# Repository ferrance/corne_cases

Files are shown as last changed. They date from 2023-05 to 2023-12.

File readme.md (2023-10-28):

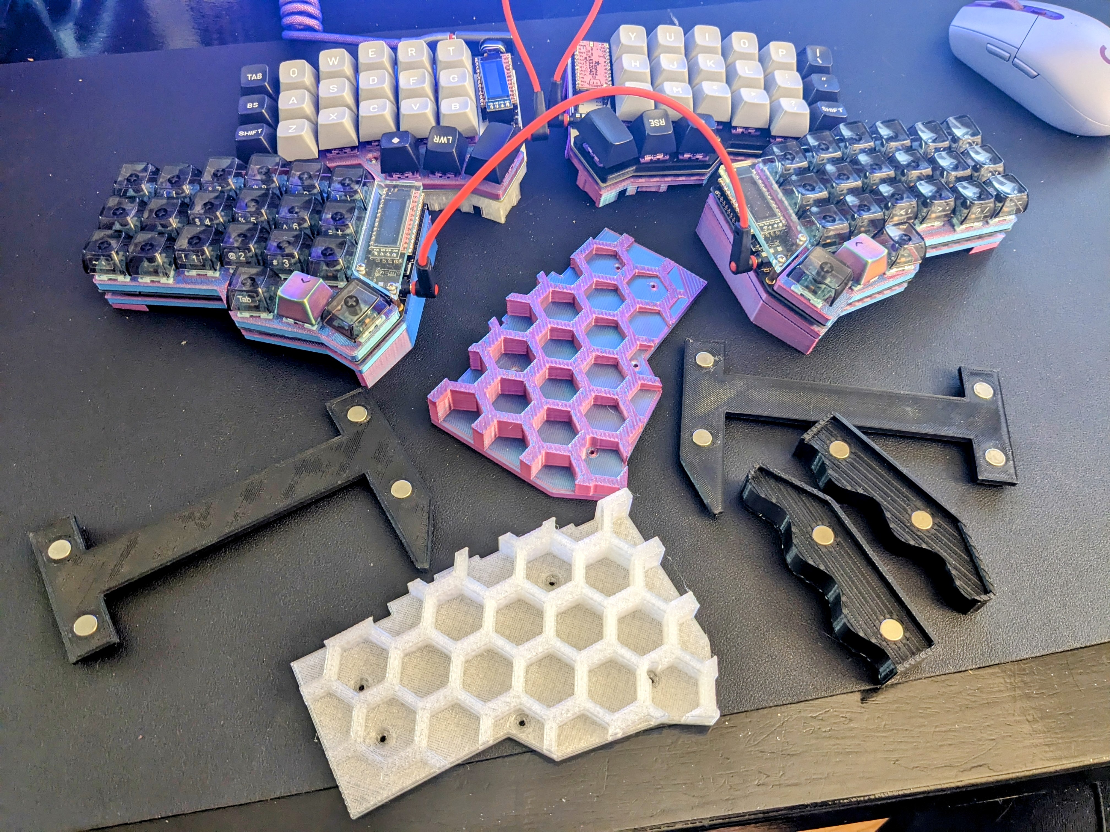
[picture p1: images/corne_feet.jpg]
image of crkbd


These are the various ways I have built my [corne keyboads](https://github.com/foostan/crkbd).
Over time it has evolved into more of a toolkit for corne-related projects in OpenSCAD.

# Source files

## crkbd.scad

This is the main library file that all of the projects are built on.

### crkbd3d(SCREWS=true)

This creates a bottom plate. It starts with the backplate_nofeet.stl file,
which it moves to a standard position in the upper right quadrant. It then
cuts out the screw holes. Doing this widens them slightly and makes sure that 
they are in the exact same spots as anything else done by this API.

### crkbd2d(SCREWS=true)

This creates a 2d profile of the PCB. The SCREWS parameter
controls whether or not it will include holes for the five
standoffs that the PCB allows for. The 2D profile is useful 
for making more complicated shapes.

This is basically a projection of crkbd3d().

## stl files
The project can be built from 3 files:
- corne_feet.scad
- cherryplate.stl
- backplate_nofeet.stl

The two STLs come from: https://thingiverse.com/thing:4459741

The scad file generates all of the other STLs.

# Projects

## stl-feet

## Pillars

This is sort of a bottom plate. It contains five pillars that are 
extruded 20 degrees around an axis to give it 20 degrees of tenting.
The pillars have holes that you can screw M2 screws into. I didn't 
thread these, they are just small enough that the screw will to that 
for you. The screws are meant to go down through the top plate and PCB
directly into the 3D printed object. 

I am using this with a fairly strange corne that i built with the 
controller on the bottom. It accomodates that nicely. This board 
also uses a 1.3" OLED. There is a separate mount for that included
in the project. But it would work just fine with normal OLEDs and controllers.

## Case

A quick and dirty box to store a corne in for travel. Before I built
this I actually lost a keyswitch and keycap when pulling the board out 
of a pocket in my laptop case. This should fix that.
# STL Files

- keyplate.stl

  the top plate that the cherry mx switches fit in. It does not
  matter what top plate you use, you can use the rest of these STLs
  with any top plate, even an FR4 or an acrylic plate.

- base_plate_flat.stl

  flat bottom plate with holes for 4 magnets. This is 
  the bottom plate to attach to keyplate.stl if you want
  to use the magnetic attachments.

- base_plate_5x5.stl

  a base plate with 5 degrees of tent ant 5 degrees of tilt.
  It does not use magnets. It is best for keebs that you don't 
  need to travel with. You can dial in an appropriate amount of
  tent and tilt in the SCAD file; 5x5 just happens to work nicely
  for me.
  
- corne_feet.stl

  These are small feet which attach via magnets to the magnetic
  bottom plate to provide some tenting.

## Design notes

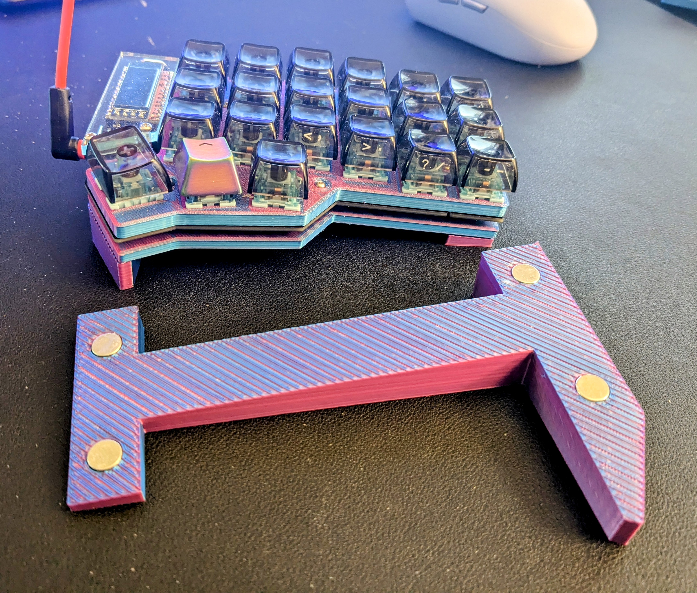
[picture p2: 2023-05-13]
images/close_up.jpg

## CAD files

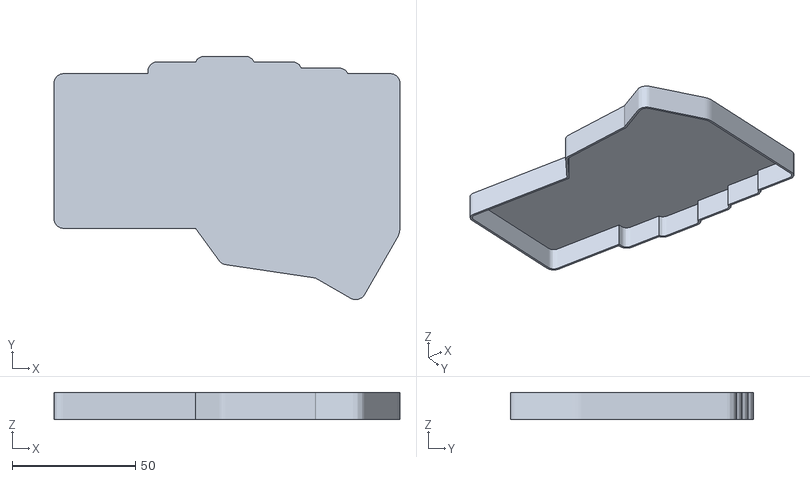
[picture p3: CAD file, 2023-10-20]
case/crkbd-cover.stl
140.2 x 98.5 x 11.0

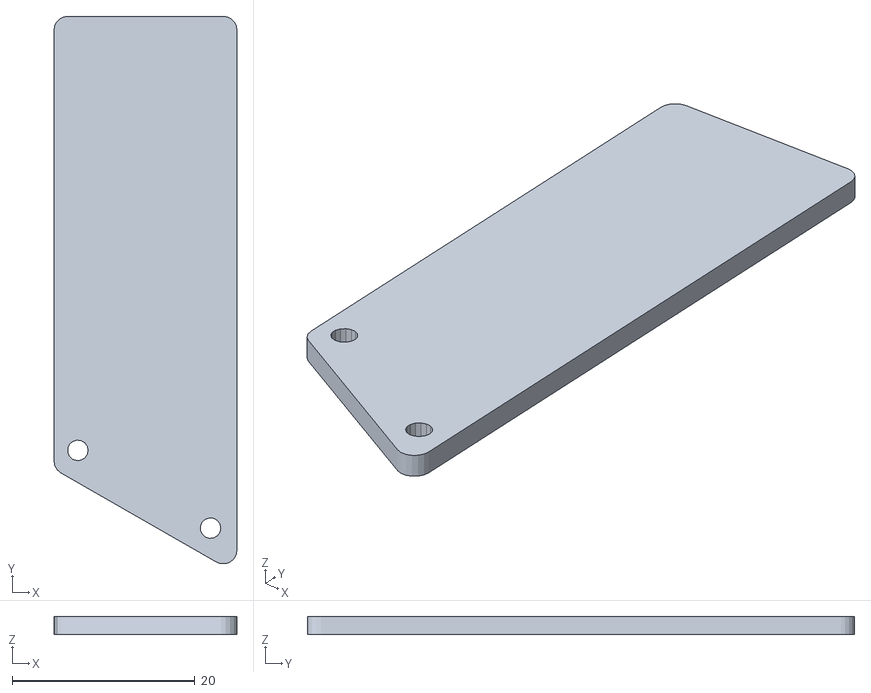
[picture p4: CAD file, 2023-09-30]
input/oled_cover.stl
20.0 x 59.8 x 2.00

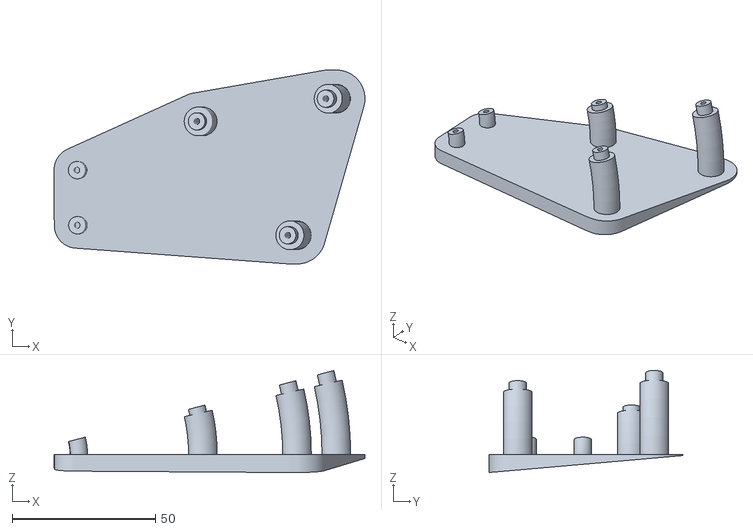
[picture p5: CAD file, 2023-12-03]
pillars/pillars-15.stl
108.4 x 67.6 x 35.6

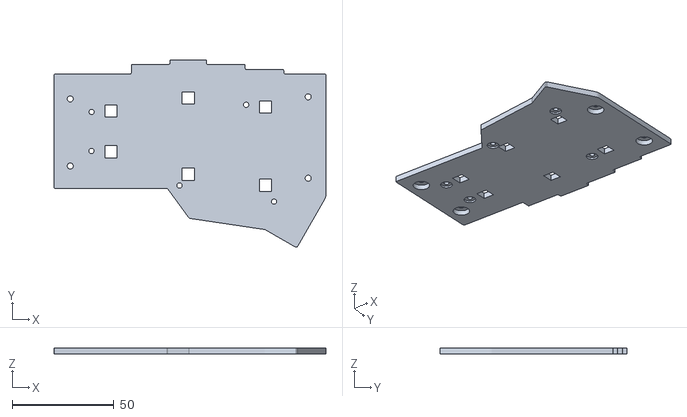
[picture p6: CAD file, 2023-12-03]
stl/base_plate_underglow.stl
133.8 x 92.2 x 3.00

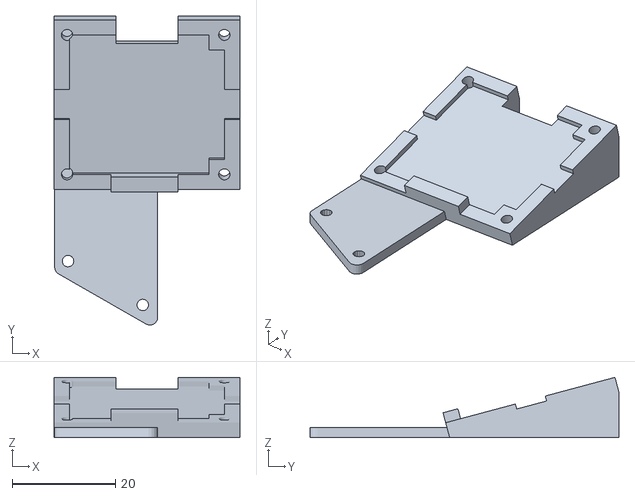
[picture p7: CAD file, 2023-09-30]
upsidedown/oled_cover_big.stl
36.0 x 59.9 x 11.7

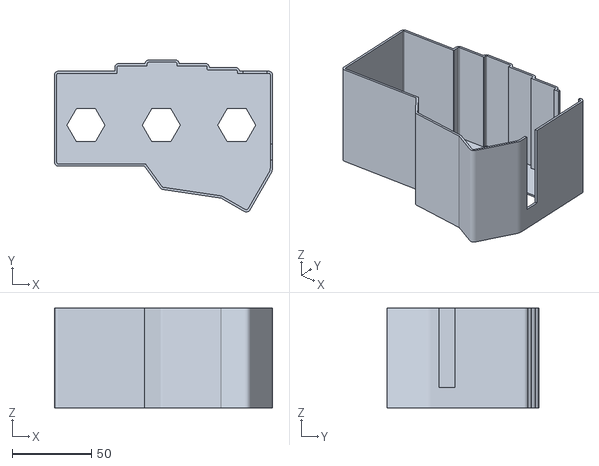
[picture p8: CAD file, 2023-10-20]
case/crkbd-case.stl
137.4 x 95.8 x 63.0

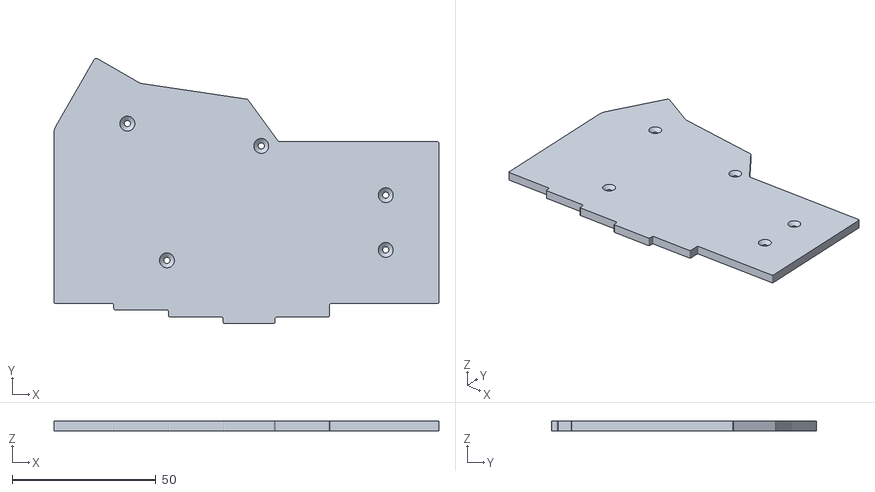
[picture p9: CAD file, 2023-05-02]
input/backplate_nofeet.stl
133.8 x 92.2 x 3.50

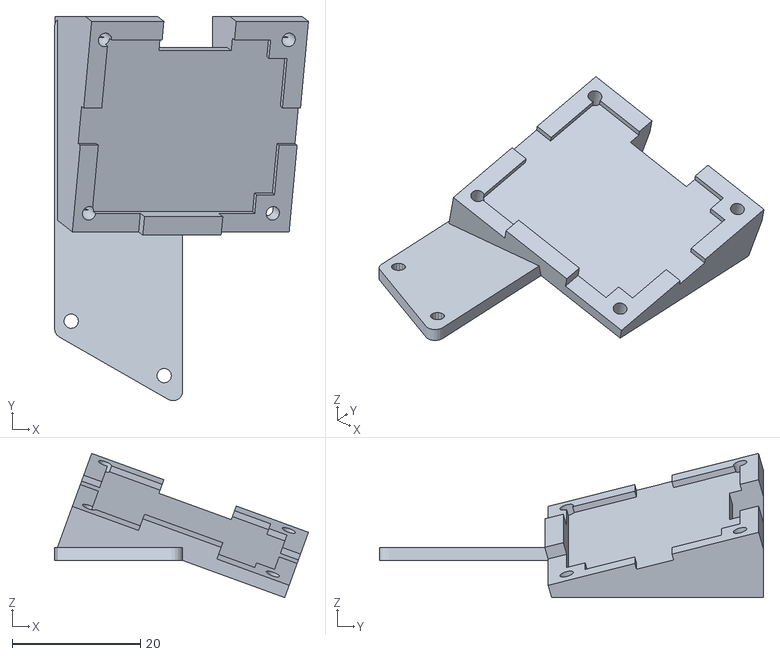
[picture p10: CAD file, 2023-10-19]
pillars/lcd-angled.stl
39.6 x 59.9 x 22.5

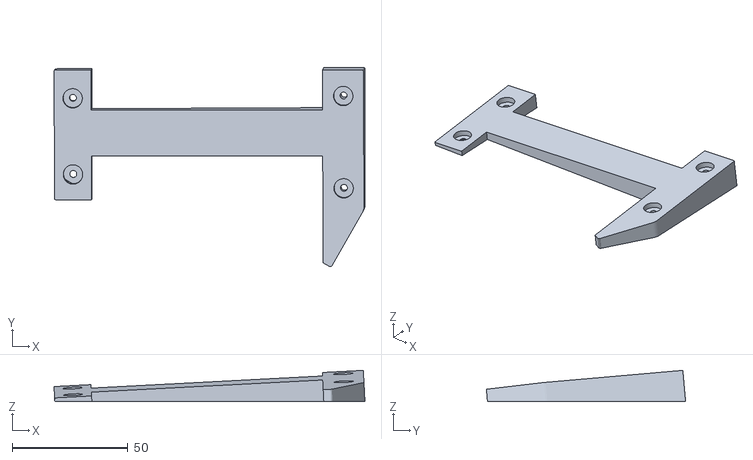
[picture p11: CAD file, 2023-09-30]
stl/base_plate_3x5.stl
134.3 x 86.0 x 13.5

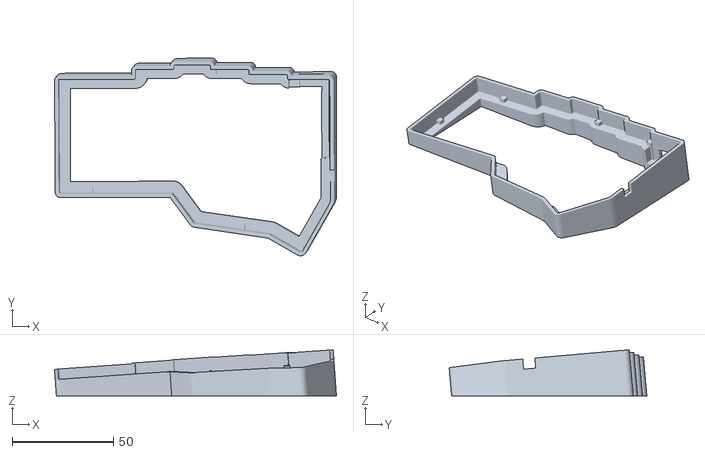
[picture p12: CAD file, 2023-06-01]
upsidedown/base_wo_ledge.stl
139.0 x 97.5 x 22.7

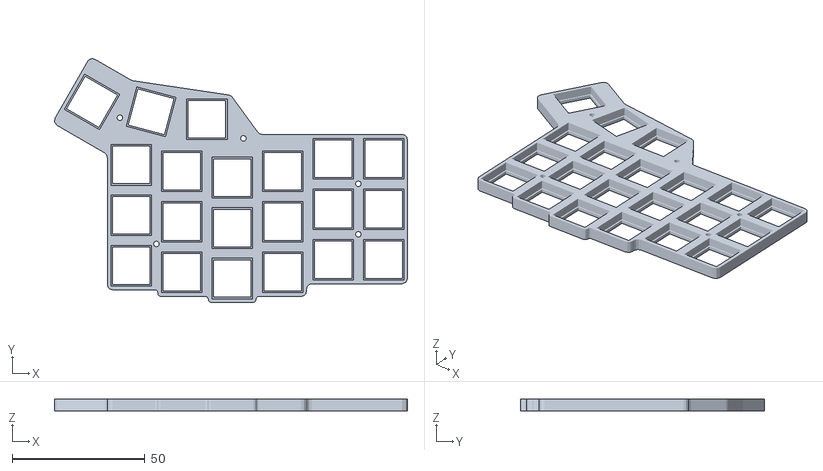
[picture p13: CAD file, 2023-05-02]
input/cherryplate.stl
132.9 x 91.8 x 4.50

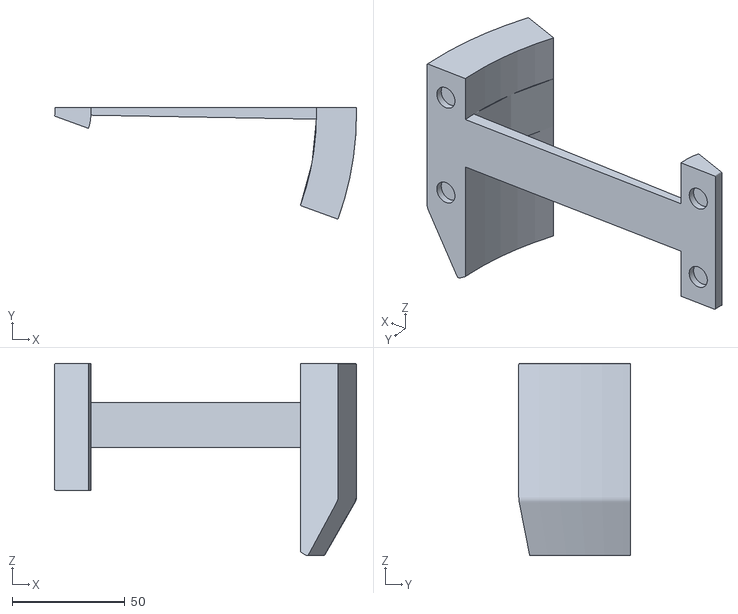
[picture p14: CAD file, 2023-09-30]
stl/base_plate_20x0.stl
133.9 x 49.4 x 85.2

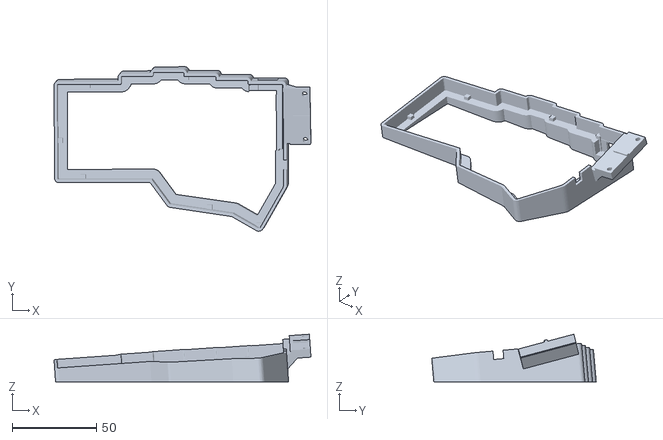
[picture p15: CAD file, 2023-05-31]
upsidedown/base.stl
152.3 x 97.5 x 28.2

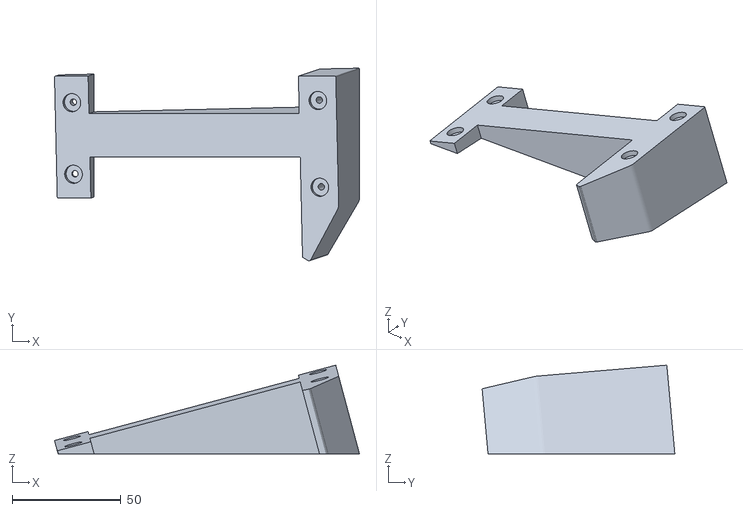
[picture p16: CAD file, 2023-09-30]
stl/base_plate_15x5.stl
140.1 x 88.5 x 40.7

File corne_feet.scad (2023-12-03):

// 2022 12 10    original design
// 2023 01 01    clean up terrible code, now it is just really bad
//               add one piece backplate and feet
//               made the ledge a little taller
// 2023 01 08    adding holes to allow magnets to be removed
//               more easily. Widen screw holes and inset them
//               got rid of the two middle magnets
// 2023 03 22    refactor everything, make a base plate with tent/tilt w/o magnets
//
// 2023 05 26    cleaning up the code
//
// 2023 09 05    adding round_magnets()
//
// 2023 12 02    added holes for underglow, refactoring
//
// Assumes these files are present:
//   - backplate_nofeet.stl (3.5mm tall)
//   - cherryplate.stl (4.5mm tall)

use <crkbd.scad>

$fn=10;

BASE_THICKNESS = 3.5;    // per slicer, measured is as high as 3.9, sigh
TOP_THICKNESS  = 4.5;    // ht of top plate
MAG_H = 2.6;  // measured ht of magnets 

// the top, with a border to snap into the bottom plate
// draws a 3.5mm high, 2mm wide border
// then subpracts a 1.5mm baseplate
// then rotates it all ANGLE DEGREES
// note that you can't put a 2.5mm magnet here because there's
// only 1mm of top to pet it in
//
// currently only called by wedge
//
module top() {
    ANGLE = 5;
    rotate([0,-ANGLE,0])
        difference() {
            linear_extrude(3.5) offset(r=2) k2d();
            translate([0,0,1]) linear_extrude(10) k2d();
        }
}

module wedge(magnets=false) {
    ANGLE = 5;
    difference() {
      union() {    
        // make a base that matches the projection of the top
        difference() {
          linear_extrude(20) projection() top();
          rotate([0,-ANGLE,0]) 
            translate([-10,0,0]) linear_extrude(30) square(200);
        }
      
        // now add the top
        top();
      } //union
      
      if (magnets) {
        rotate([0,-ANGLE,0]) translate([0,0,-1.59]) magnets();
      }
  } // difference

}

// these are the feet that attach to the insidbe magnets
// to provide some tenting
// 
// this was my original idea for tenting and portability. it
// still works but I prefer the full base with the built in magnets now
//
module corne_feet(magnets=false) {
    difference() {
        wedge(magnets);
        
        linear_extrude(20) translate([114,150,-0.01]) 
          rotate([0,0,-90]) polygon(sinewave(3,150,5));
        translate([0.01,0,-1]) linear_extrude(20) square([114,200]);
        translate([-2,0,0]) linear_extrude(20) square([10,200]);

    } 
}

// bottom plate with buit in tenting
module one_piece() {
    //corne_feet();
    rotate([0,-5, 0]) crkbd3d();
    color("red") 1piece_wedge();
}    


// this is the base plate with optional integral tent/tilt
//
// ht = ht/thickness of base plate. prob shld always be 3.5 
// tent = tent angle
// tilt = tilt angle
// magnets = true for magnet holes, false for no magnet holes
// ZOFS = move up or down before chopping. use to adjust final ht
//
// Make a big chunk shaped like a base plate
// rotate it by the tent and tilt
// allow height adjustment
// then chop off everything below z=0
//
module base_plate(ht=3,tent=0,tilt=0,MAGNETS=true,ZOFS=0,UNDERGLOW=true) {
    BIG = 40;
    
    chop(t=[0,0,ht-BIG+ZOFS], r=[tilt, -tent, 0] )
    { 
        // giant k2d with holes
        difference() {        
            linear_extrude(BIG) crkbd2d();
            if (MAGNETS) {
                translate([0,0,BIG-ht]) magnets();
            }
            screw_holes(HT=BIG);
            
            if (UNDERGLOW) 
                underglow();
            
            // remove material for aesthetics and maybe print time
            if (true) {
                translate([-18,5,0]) hex_grid(BIG-ht);
            }
        }
    }  // chop    
}

// this creates a magnetic attachment that can attach to
// the bottom of a base plate. It can have varying degrees
// of tent and tilt.
//
// This is useful if you travel with the keeb because it allows
// you to remove the angled part and have a flat (easy to carry)
// keeb
//
// if you don't travel, you could just create a one piece angled base 
// plate
//
// ht = thickness of plate if plate is flat. if not flat, then play
//      with this parameter to get the height you want.
//
module flat_magnets(ht=3,tent=0,tilt=0, SCREWS=true) {
    BIG=100;
    
    chop(r=[tilt, -tent, 0], t=[0,0,ht-BIG])
    {                
        // make a giant k2d shaped block w holes
        difference() {
            linear_extrude(BIG) crkbd2d(SCREWS=SCREWS);
            translate([0,0,BIG]) mirror([0,0,1]) magnets(SCREWS=SCREWS);
            translate([18,0,0]) linear_extrude(BIG+1) square([100,200]);
        }
        
        // add crossbar
        translate([18,50,0]) linear_extrude(BIG) square([100,20]);
    } // chop
}

module round_magnets(ht=3,tent=0,tilt=0) {
//    ANGLE = 20; OFS = .2;
    ANGLE = 25; OFS = 1;
//    ANGLE = 30; OFS = 1;

    rotate([90,0,0]) {
    
        difference() {
            rotate_extrude(angle=ANGLE, $fn=300)
                projection()
                    flat_magnets(SCREWS=false);
            rotate_extrude(angle=ANGLE - 1, $fn=300)
                translate([18,50,0]) square([100,20]);    
        }
        
        // put the top on it
        translate([0,0,8.61])
        rotate([90,0,ANGLE])    
            mirror([0,0,1])
                color("blue") flat_magnets(OFS,0,5,SCREWS=false);

    }

}

//uncomment one of these:

// These are feet that go on the inside to create tent.
// Right now they create no tilt.
//corne_feet(magnets=true);  // magnets=false for no magnets

// This base attaches magnetically to the base plate.
// It has no snap in borders. Can be configured with
// different tent and tilt. It is not a great travel 
// option but it is what I use on my desktop.

//flat_magnets();            // flat magnet base 3mm tall
//flat_magnets(-0.4,5,5);      // base plate with tilt and tent
//flat_magnets(-0.4,3,5);      // base plate with tilt and tent
                             // this is my preferred option

//flat_magnets(2,15,5);

// This is a base plate with built in tent and tilt. 
// It does not require magnets and a separate base, so
// it can be thinner. but it is less adjustable. 
//
//base_plate(); // flat base plate with magnets
//base_plate(3.5,5,5,false,-4); // tented,tilted plate w/o mags
base_plate(UNDERGLOW=true);


// The top plate for cherry mx switches
// The only thing this changes from the original is to
// counterbore instead of countersinking the screws, since
// I found it hard to keep the standoffs at right angles to 
// the plate with the original design.
//
//top_plate();



// for testing:
//crkbd3d();
//crkbd2d();
//translate([0,0,BASE_THICKNESS]) mirror([0,0,1]) screw_holes(HT=BASE_THICKNESS);
//magnets();
//mirror([0,0,1]) magnets();
//hex_grid(45);



//round_magnets(2,15,5);

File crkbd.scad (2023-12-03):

// 2023 05 29    put shared functions in this library
//
// Assumes these files are present:
//   - backplate_nofeet.stl (3.5mm tall)
//   - cherryplate.stl (4.5mm tall)
//
// functions:
//
// sinewave
// hex_grid
// chop
//
// screw_holes
// magnets
// crkbd3d
// crkbd2d
//

$fn=50;

BASE_THICKNESS = 3.5;    // per slicer, measured is as high as 3.9, sigh
TOP_THICKNESS  = 4.5;    // ht of top plate
MAG_H = 2.6;  // measured ht of magnets 

// sine wave used to make the feet look nicer
function sinewave(radius,length,waves) = [
            [0,0], 
            for (phi = [1 : 6 : 360*waves]) 
                [length*phi/(360*waves), radius + radius * sin(phi)],
            [length,0]
                
    ];

// grid of hexagons to subtract from things
module hex_grid(ht) {
    CR = 10;
    D = 3;
    translate([150,0,0]) rotate([0,0,90])
    for (y=[0:8] ) {
        for (x=[0:7] ) {
            translate([x*(2*CR+D) + (y%2)*(CR+D/2), y*(2*CR)*.9,0])
            color("blue") rotate([0,0,30]) cylinder(r=CR, h=ht, $fn=6);
        }
    }
}

// a helper that rotates and translates, then chops off 
// everything below z=0
//
module chop(t=[0,0,0],r=[0,0,0])
{
    HT = 100;
    difference() {
        translate(t)
        rotate(r)

        children();
        color("red") translate([-500,-500,-HT]) linear_extrude(HT) square(1000);
    }
}

// these are where the screws are on CRKBD
// you can subtract this from a volume to get countersunk
// holes for the screws
//
// it is oriented the same was as k3d and k2d
//
// most of the cylinder is countersunk because it is 
// expected that the screws will always be small (around
// 4mm) but the countersink depth will vary depending on
// what they are in
//
//   R  = inner diameter
//   R2 = outer diameter
module screw_holes(R=1.3, R2=3, HT=25) {
    OFS = BASE_THICKNESS-1.5;
    HOLES = [ [20.4,49.4], [20.5,68.6], [96.5,72.1], 
              [63.7,32.4], [110.2,24.5]
    ];
    
    for (h=HOLES) {
        translate([h[0],h[1],0]) {
            color("blue") cylinder(r=R, h=HT);
            color("green") cylinder(r=R2, h=HT-OFS);
        }
    }
}    

// four holes for magnets
// subtract out as necessary
module magnets(SCREWS=true) {
    MAG_R = 4.2;  // 4.05 was a a little too tight
    SMALL_R = 1.5;
    BIG = 50;
    MAGNETS = [[127,36,0], [127,76,0], [10,75,0], [10,42,0]];
    
    // each magnet hole has a hole for the magnet and
    // a thinner hole to facilitate getting the magnet
    // out if the hole is a tight fit
    for(m=MAGNETS)
        translate(m) {
            translate([0,0,MAG_H-BIG]) cylinder(r=MAG_R,h=BIG);
            if (SCREWS) {
                cylinder(r=SMALL_R, h=BIG);
            }
        }
}

// six holes for the underglow LEDs
module underglow()
{
    LEDS = [ 
                // pinky
               [27,46,0],
               [27,66,0],
    
                // middle
               [65,35,0],
               [65,72.5,0],
    
                // index
               [103,29.5,0],
               [103,68,0]
            ];

    for (l=LEDS)
        translate(l)
            cube([6,6,100]);
}

module top_plate() {

    chop() 
    difference() {

        union() {
            translate([4,2,4.5]) 
            rotate([0,180,0])
            translate([0, 31, 0 ]) 
                mirror([0,1,0])
                    import("input/cherryplate.stl");
            
            // fill in the screw holes in the input STL,
            // we will remove them again below
            screw_holes(HT=4.5, R=2.6, R2=2.6);
        }
        
        // widen the screw holes
        // but don't inset them, it isn't necessary and it
        // complicates the printing
        translate([0,0,5]) 
            mirror([0,0,1]) 
                screw_holes(HT=5,R=1.3, R2=1.3);        

        // square off the top edges
        if (true) {
            color("green") translate([35,87,0]) linear_extrude(10) square(5);
            color("green") translate([54,91.8,0]) linear_extrude(10) square(5);
            color("green") translate([77,91.8,0]) linear_extrude(10) square(5);
            color("green") translate([96,89.3,0]) linear_extrude(10) square(5);
        }
        
    } // diff
        
}

// this just imports the bottom plate and positions it
// the bottom plate has screw holes that are a little tooes
// small and that are countersunk wrong for the type of 
// screws I have, so I ended up redoing the holes 
//
// you can use this by itself as a bottom plate
//
// this is about 3.9mm thick
//
module crkbd3d(SCREWS=true) {
      
    difference() {

        translate([2,0,3.5]) rotate([0,180,0])
            translate([0, 31, 0 ]) 
                mirror([0,1,0])
                    import("input/backplate_nofeet.stl");
        
        // widen the screw holes
        screw_holes(HT=BASE_THICKNESS);
            
    } // diff
}

// 2d projection of the botom plate
// there are no screw holes
module crkbd2d(SCREWS=true) {
    projection() {
        crkbd3d(SCREWS=SCREWS);
        screw_holes(); 
    }
}

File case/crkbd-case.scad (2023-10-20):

use <../crkbd.scad>

H=62; // should be 60

module box() 
{
    difference() {
        // original offsets were 2 and .8 - too loose
        // 1.8 and .2 - too tight
        linear_extrude(H+1) offset(r=1.8) crkbd2d();
        translate([0,0,1]) linear_extrude(H+1) offset(r=.4) crkbd2d();

        // cutout for cable
        translate([130,33,13]) color("red") cube([10,10,H]);
        
        // cutout for usb
        translate([119,80,13]) color("red") cube([15,15,H]);
        
        // finger holes
        translate([20,55,-1]) cylinder(r=12,h=H, $fn=6);
        translate([67.5,55,-1]) cylinder(r=12,h=H, $fn=6);
        translate([115,55,-1]) cylinder(r=12,h=H, $fn=6);
    }
}

module cover() 
{
    difference() {
        linear_extrude(11) offset(r=3.2) crkbd2d();
        translate([0,0,1]) linear_extrude(H+1) offset(r=2.2) crkbd2d();
    }
}


//box();
translate([0,-110,0]) mirror([0,0,1]) cover();

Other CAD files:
upsidedown/lcd_1_3.stl
stl/base_plate_round_20x5.stl
stl/base_plate_round_25x5.stl
stl/top_plate.stl
top_plate.scad
pillars/pillars.scad
stl/base_plate_5x5.stl
stl/base_plate_flat.stl
stl/corne_base_magnets.stl
stl/corne_feet.stl
stl/corne_flat_magnets.stl
stl/corne_wedge_5x5.stl
stl/one_piece.stl
upsidedown/corne_upsidedown.scad

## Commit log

2023-05-13 working on key plate
    [base_plate_5x5.stl, corne_feet.scad, keyplate.stl]
2023-05-26 cleaning up the scad code
    [corne_feet.scad]
2023-06-01 making ledge optional
    [base_wo_ledge.stl, corne_upsidedown.scad]
2023-10-19 working on case
    [crkbd-case.scad, crkbd-case.stl, lcd-angled.stl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]
2023-12-03 refactor, add underglow
    [backplate_nofeet.stl, base_plate_15x5.stl, base_plate_20x0.stl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]
